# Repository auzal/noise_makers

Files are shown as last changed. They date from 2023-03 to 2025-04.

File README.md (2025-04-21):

# Protest noise makers

Simple 3D printable noise makers. Use for fighting colonialism, fascism and unfair labor practices. 

Developed during the UCLA Graduate strike of 2022. More info [here](#background).

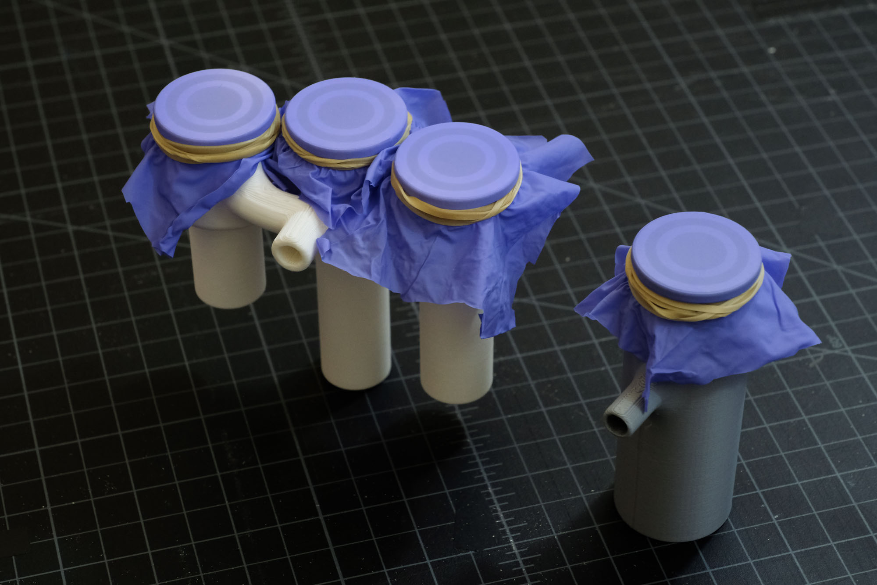
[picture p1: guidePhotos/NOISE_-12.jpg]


## Table of contents:

- [3D printable files](#3d-printable-files)
- [Assembly guide](#assembly-guide)
- [Test videos](#test-videos)
- [Design](#design)
- [Variations](#variations)
- [Earlier versions](#earlier-versions) 
- [Background](#background)

## 3D printable files

Ready to print .stl files are located in the [3DprintFiles](3DprintFiles) directory. 

There are several files that are ready to print: 
- [NoiseMakerSimpleV2.stl](3DprintFiles/NoiseMakerSimpleV2.stl) is a single chamber model. Easiest and quickest to print. This is a slightly improved version that uses less material and prints faster.
- [NoiseMakerTriple.stl](3DprintFiles/NoiseMakerTriple.stl) is a triple chamber model. Much louder and creates a poly tonal sound. Uses much more material to print. 
- [NoiseMakerSimpleV2Large.stl](3DprintFiles/NoiseMakerSimpleV2Large.stl) is a larger version of  the single chamber model. 
- [NoiseMakerSimpleV1_olderVersion.stl](3DprintFiles/NoiseMakerSimpleV1_olderVersion.stl) is an older version of the single chamber model (the one referenced in the guide photos below). It's a little less efficient than the V2 files. 

It's better if the files are printed with support material for the mouthpiece only. This can be done by using support painting or a similar tool (dependent on your 3D printing software)

## Assembly guide

A video of the assembly process can be found [here](https://youtu.be/jMzxnDv2O78)

#### Step 1 - Print a noise maker body
These devices are printed as a single piece. 
Some notes on the printing process:
- all tests have been made with PLA
- prints have been tested up to .28 mm layer height. They should work up to .4 mm
- the mouthpiece will need supports. Make sure to not include support inside the chambers or it may be difficult to remove
- an infill of about 15% is more than enough

#### Step 2 - Gather materials
To build a noise maker, you will need:
- a 3D printed noise maker body (using the single chamber model for this guide)
- some sandpaper (something like 150 grit works well)
- a pair of scissors
- a rubber band
- a nitrile glove (latex gloves, balloons, or plastic bags can also be used. Different materials will produce different timbres) 

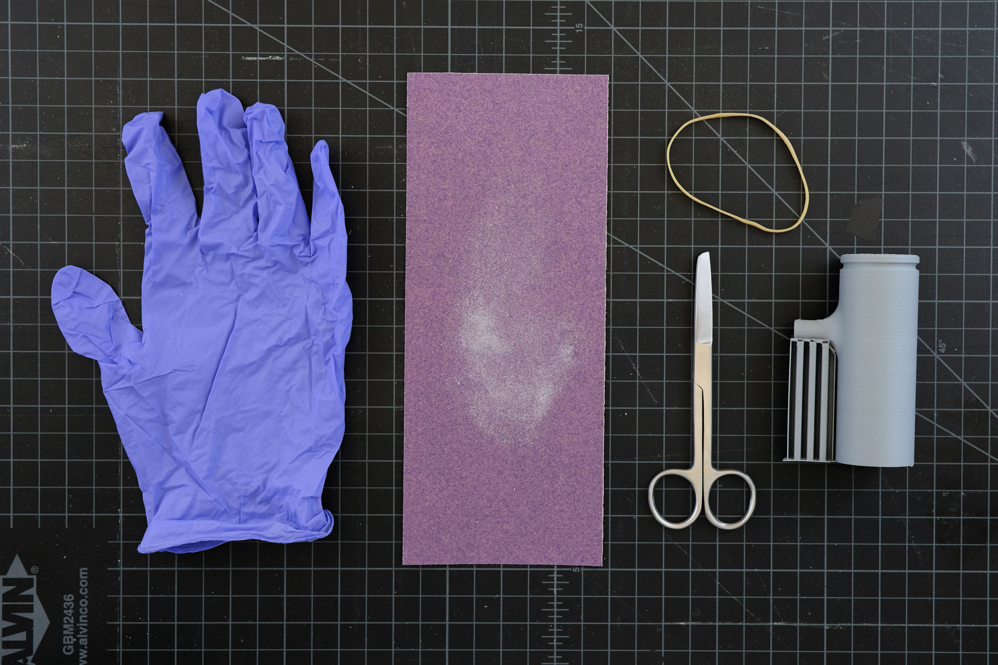
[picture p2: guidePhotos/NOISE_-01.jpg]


#### Step 3 - Remove supports from 3D printed body
 
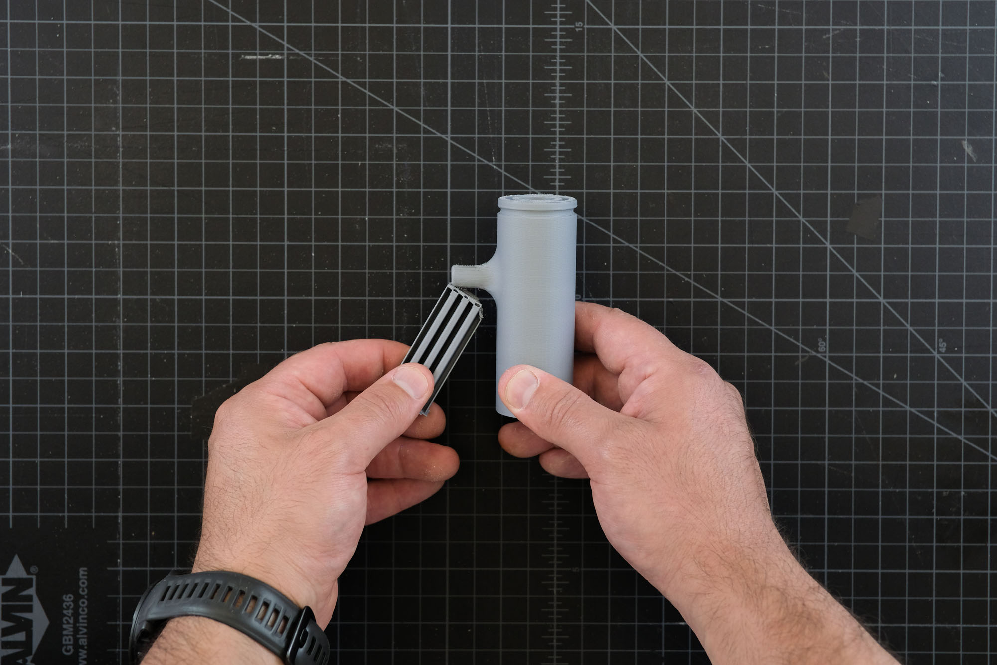
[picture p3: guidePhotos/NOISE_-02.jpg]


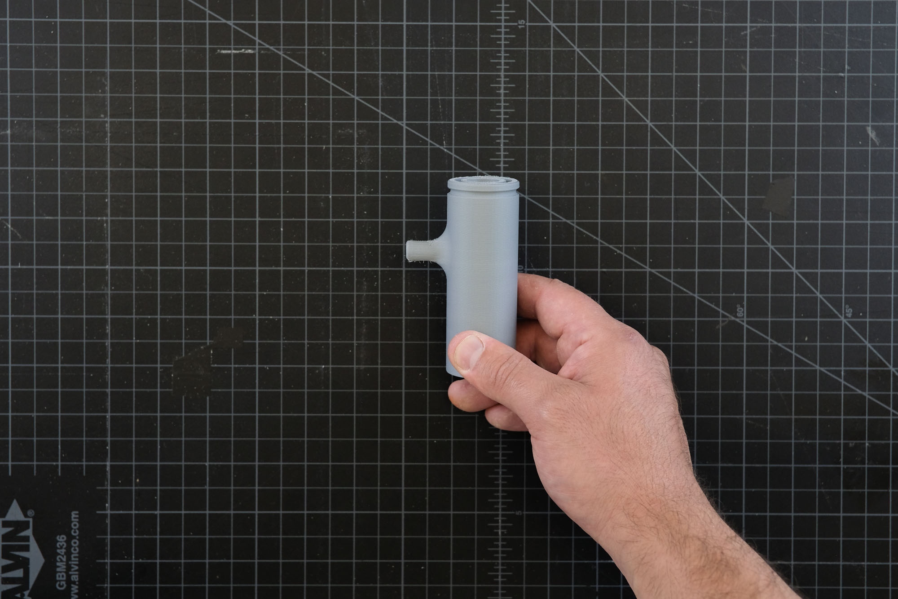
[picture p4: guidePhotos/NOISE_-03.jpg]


#### Step 4 - Sand the upper end of the body, until there are no sharp irregularities

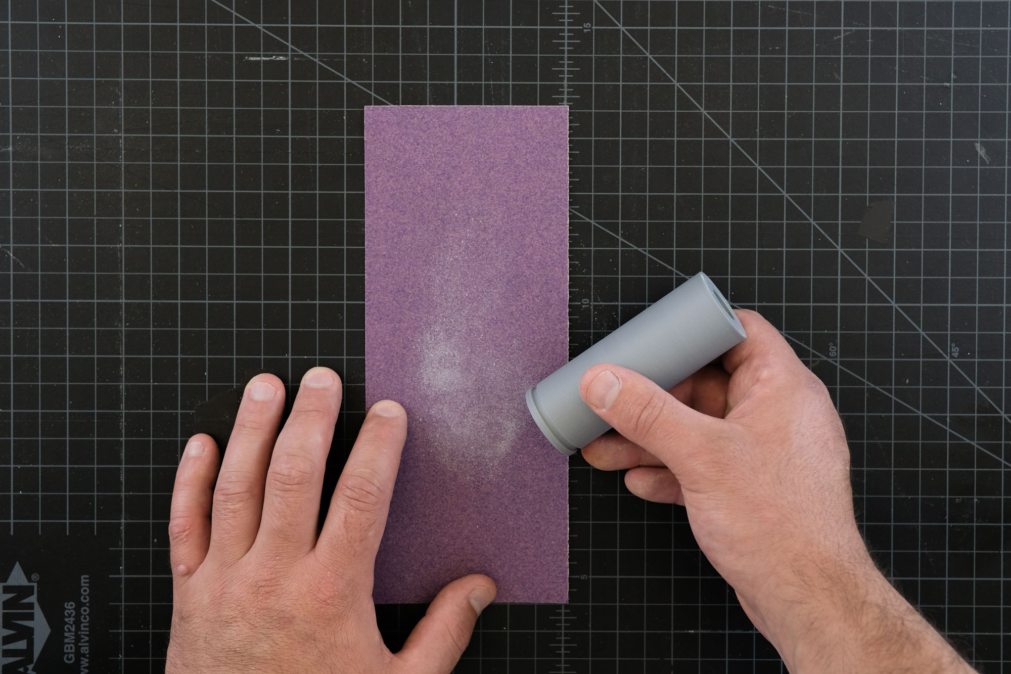
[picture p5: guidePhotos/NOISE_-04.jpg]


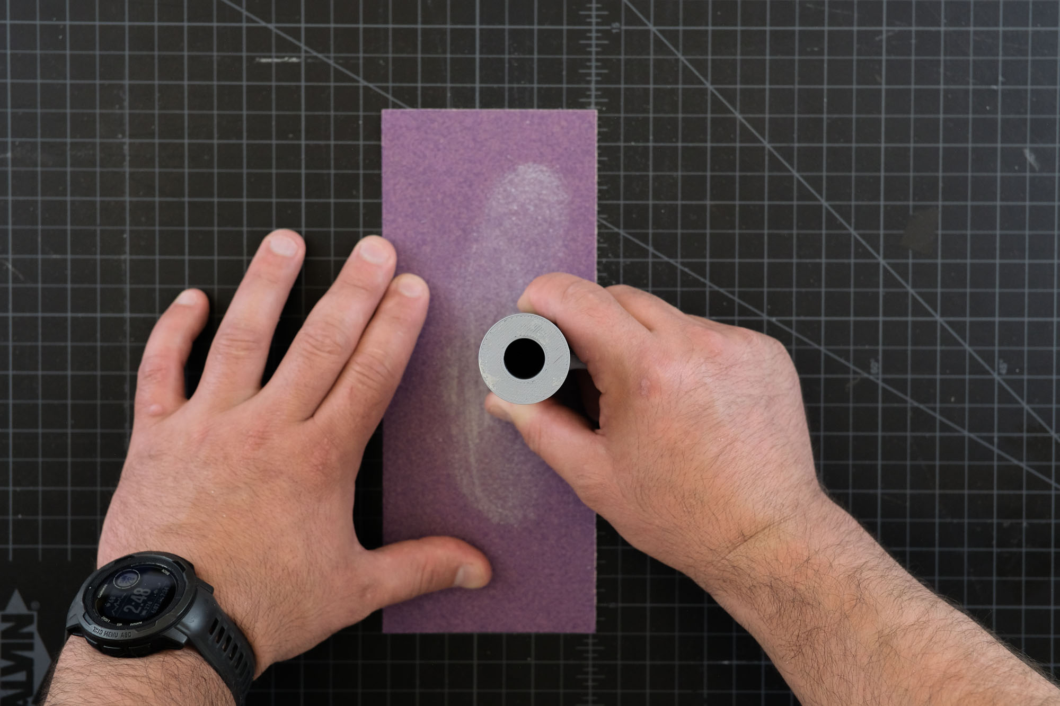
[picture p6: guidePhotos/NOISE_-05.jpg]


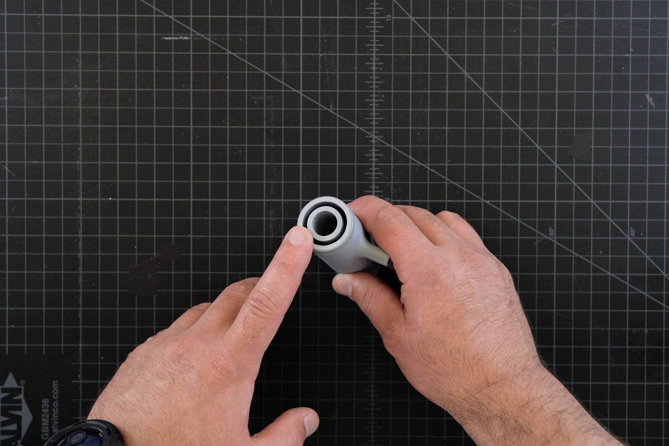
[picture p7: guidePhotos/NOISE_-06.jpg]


#### Step 5 -  Cut a square of material from the glove. It needs to be bigger than the diameter of the body. This will act as the vibrating membrane.

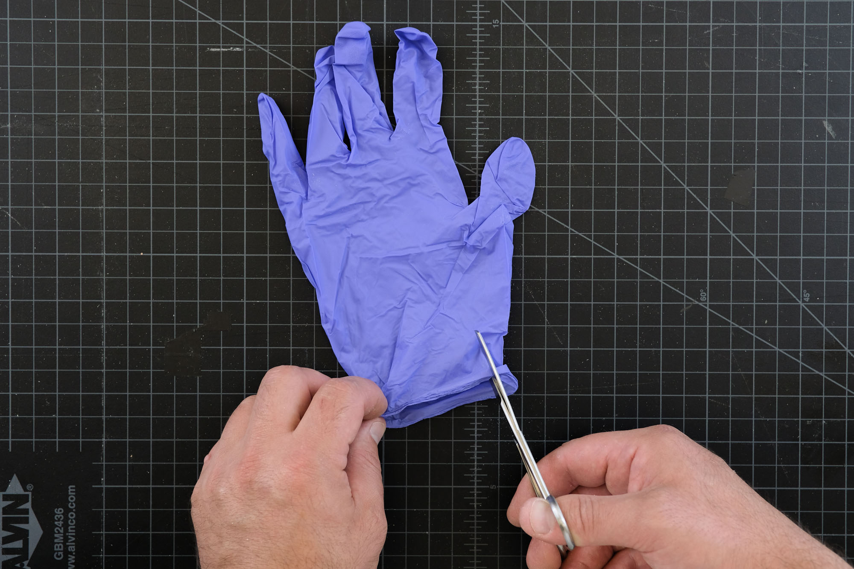
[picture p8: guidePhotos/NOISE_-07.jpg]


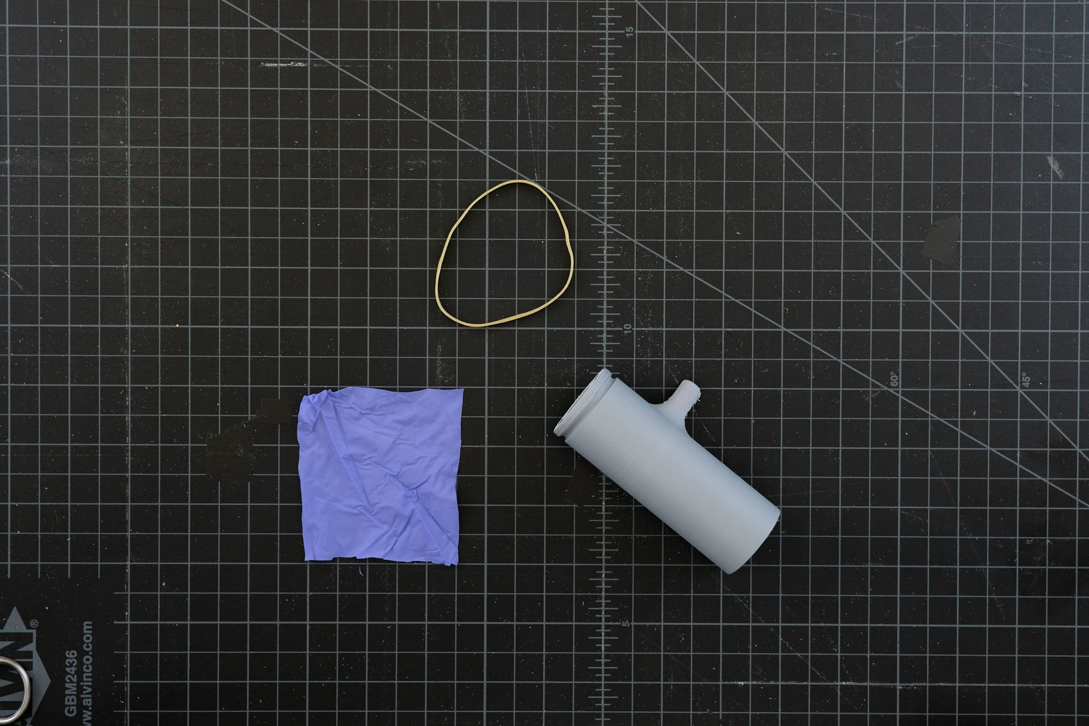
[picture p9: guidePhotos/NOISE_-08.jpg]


#### Step 6 - Stretch the membrane over the sanded end

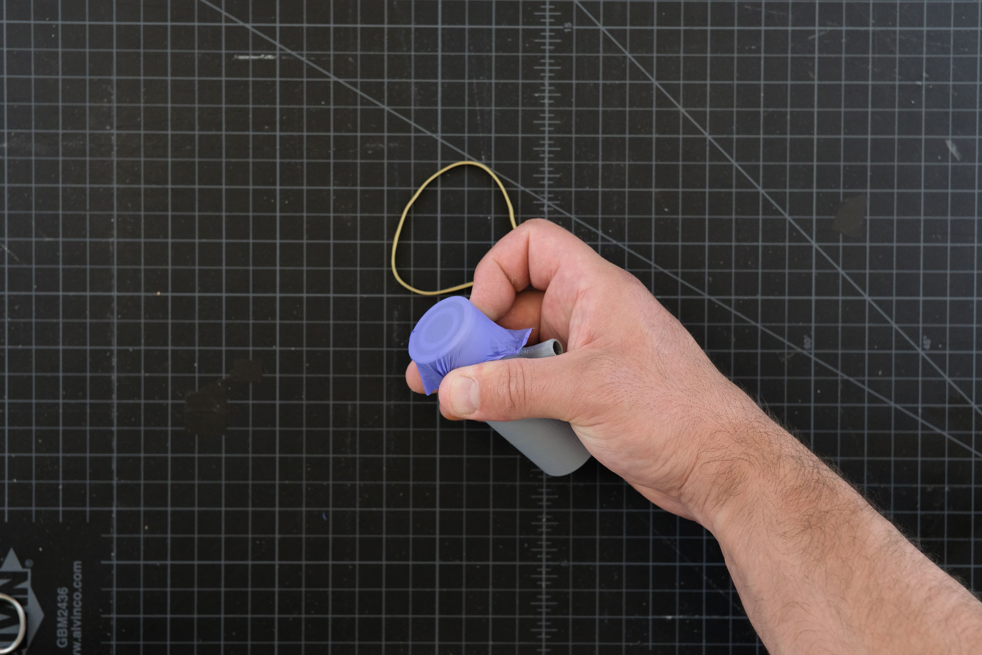
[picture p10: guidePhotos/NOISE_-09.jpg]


#### Step 7 - Secure the membrane with the rubber band. Make sure it's tight and that there are no creases.

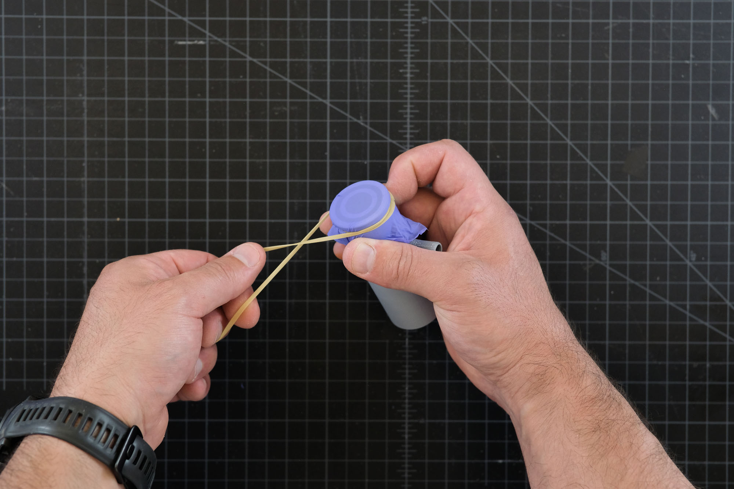
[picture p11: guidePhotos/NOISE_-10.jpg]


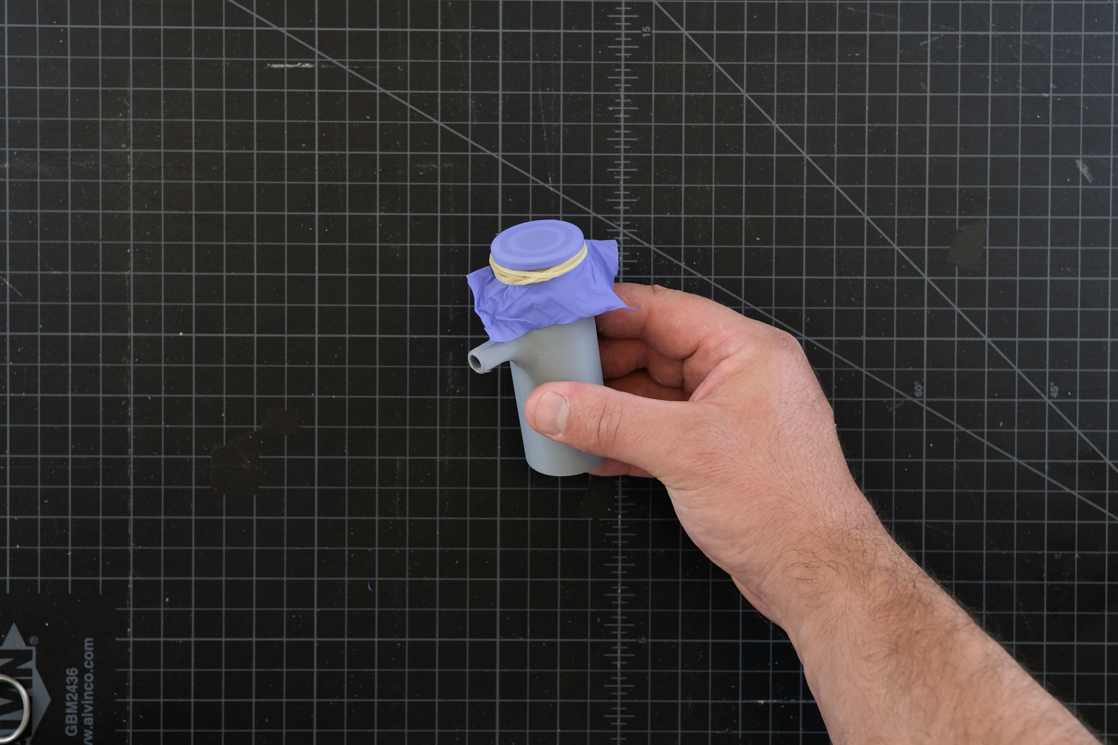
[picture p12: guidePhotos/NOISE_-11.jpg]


### Done!

## Test videos

https://github.com/auzal/noise_makers/assets/3940167/49ffc315-b2f3-4ef4-8d3e-ae68fc700136

Testing the single chamber version

https://github.com/auzal/noise_makers/assets/3940167/70f62b58-36f9-45e0-9690-6776add53538

Testing the triple chamber version

## Design

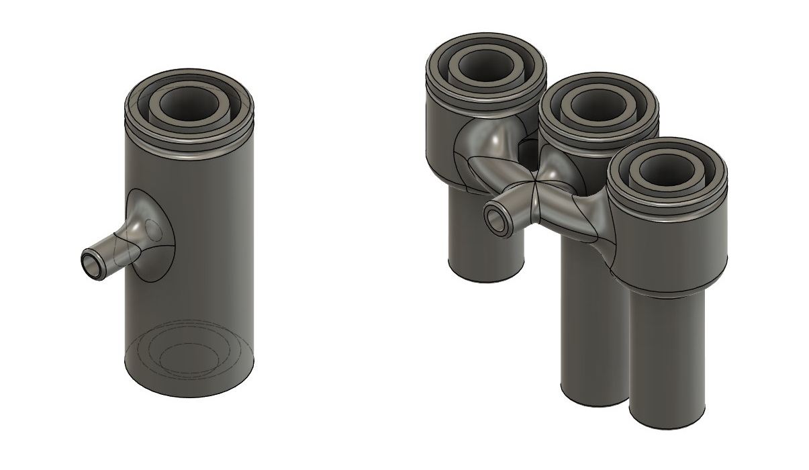
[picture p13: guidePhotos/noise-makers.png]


These devices work by blowing air through the mouthpiece. The air is then forced through an elastic membrane, which vibrates and pushes the air out of the inner tube, creating a loud sound. 

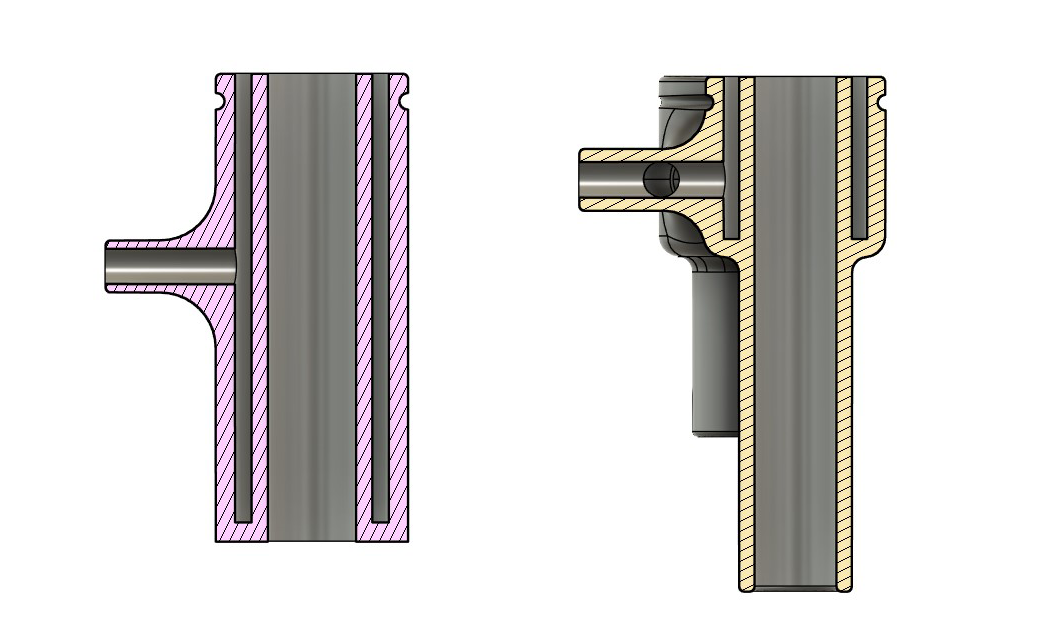
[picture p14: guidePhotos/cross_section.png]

Cross section view of both devices

These devices were modeled in Fusion 360. The design files can be found in the [fusionFiles](fusionFiles) directory. 

### Some notes on the Fusion files:
- changing the diameter of the chambers will affect the amplitude of the sound
- changing the length of the inner tube will affect the pitch (shorter tube means higher pitch)
- on the triple chamber design, the length of each inner tube can be adjusted individually
- the design is parametric, so dimensions are easy to change:
    - in the *Solid* tab, go to Modify > Change parameters 
    - from here you can adjust the diameter and overall length of the noise maker

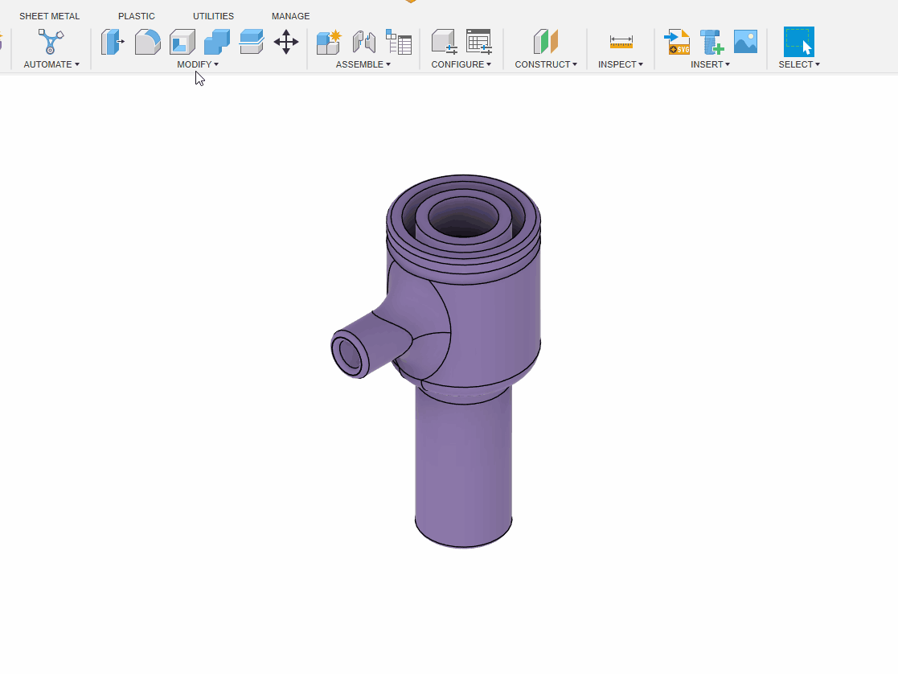
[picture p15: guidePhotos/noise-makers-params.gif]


## Variations

The single chamber noise maker can be printed to fit directly on different cylindrical objects. This will allow you to achieve lower frequencies and louder volumes. Experiment with what you have around! Make sure you seal the joint so no air can escape. 

### Bass version

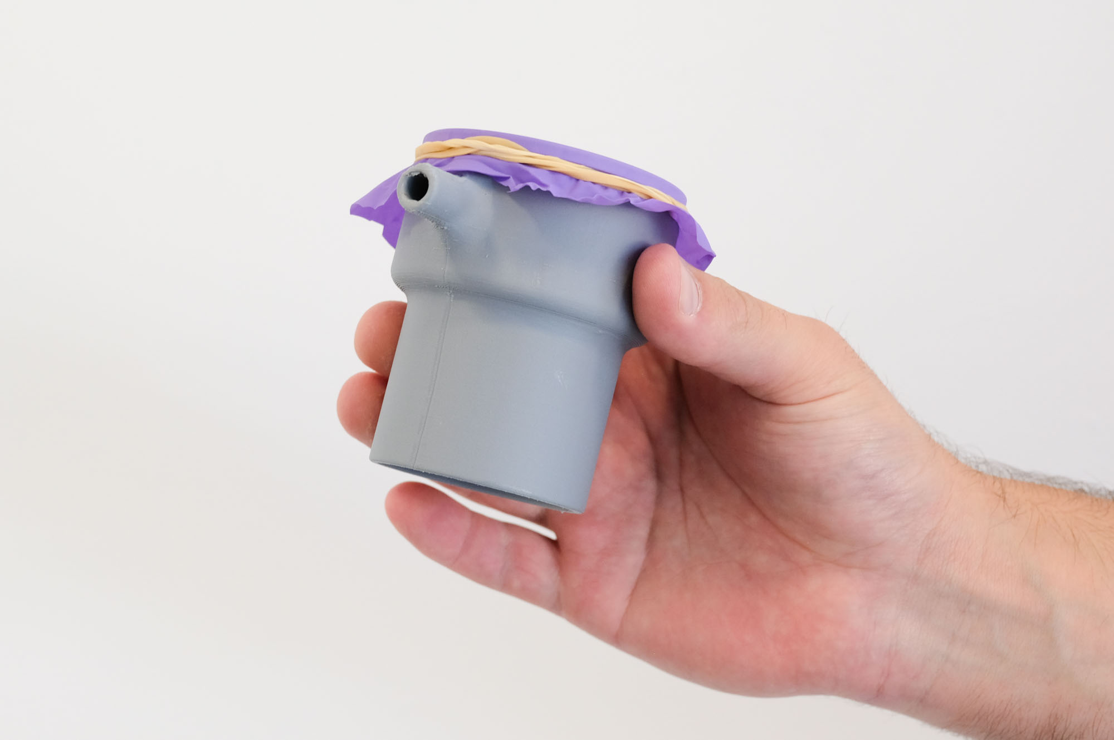
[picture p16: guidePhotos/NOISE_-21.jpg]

Single chamber design sized to fit into a 2 inch PVC pipe.

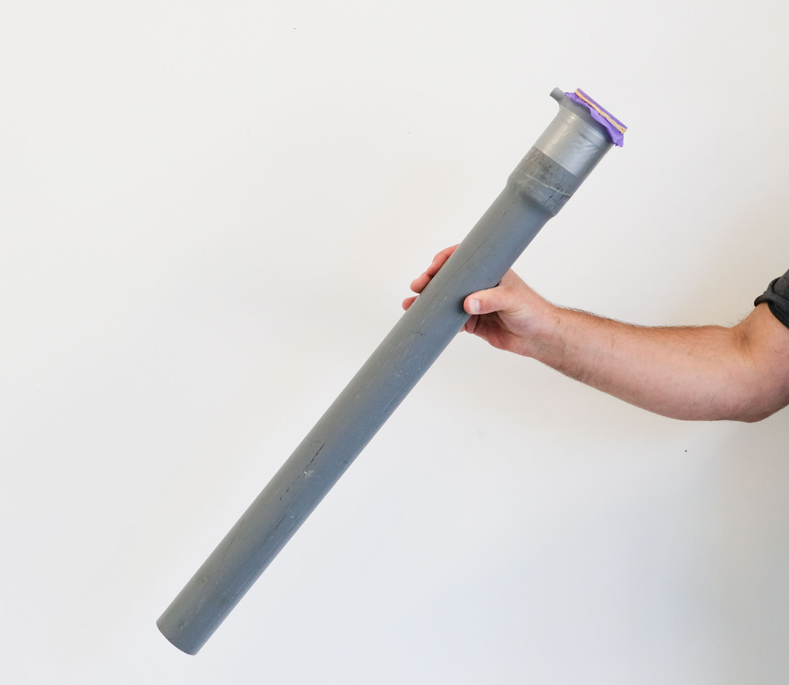
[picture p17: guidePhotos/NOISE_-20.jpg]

Fitted into a section of pipe and sealed in place with duct tape.

https://github.com/auzal/noise_makers/assets/3940167/308d74f6-2402-479b-8176-515639adbdc4

### Sliding bass version

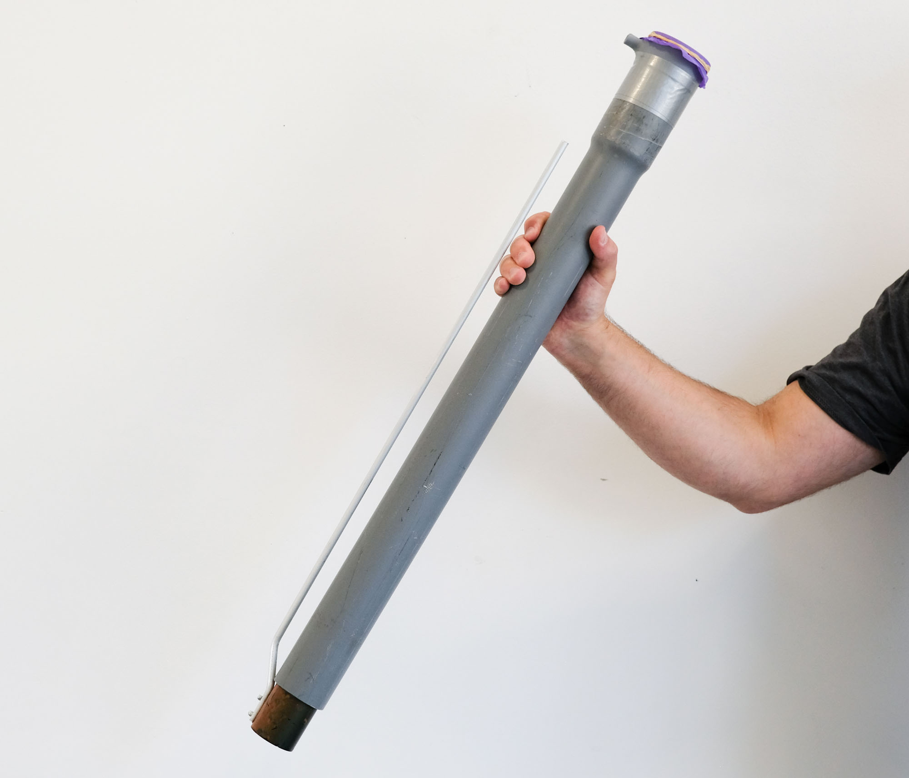
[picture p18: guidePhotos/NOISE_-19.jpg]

Same as above, but with a section of narrower pipe (fitted with a handle), that can slide to alter the pitch as it is being played (the longer the pipe, the lower the pitch).

https://github.com/auzal/noise_makers/assets/3940167/3bd1a570-b454-4dcb-a997-6549486a73a5

### Water jug version

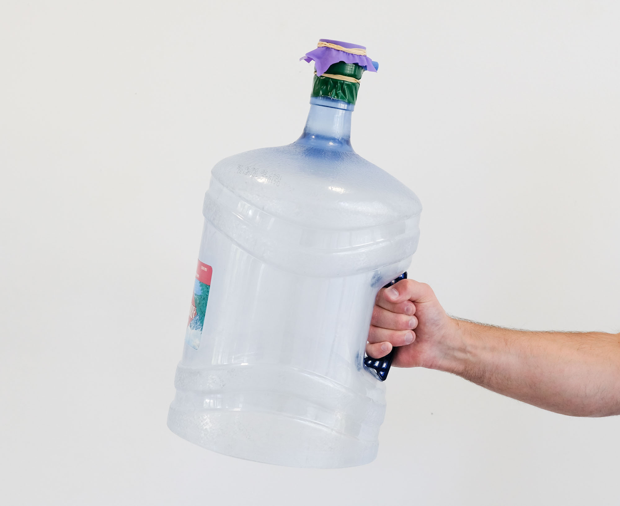
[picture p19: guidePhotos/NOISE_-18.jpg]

Single chamber design sized to fit into a plastic 5 gallon water jug. 

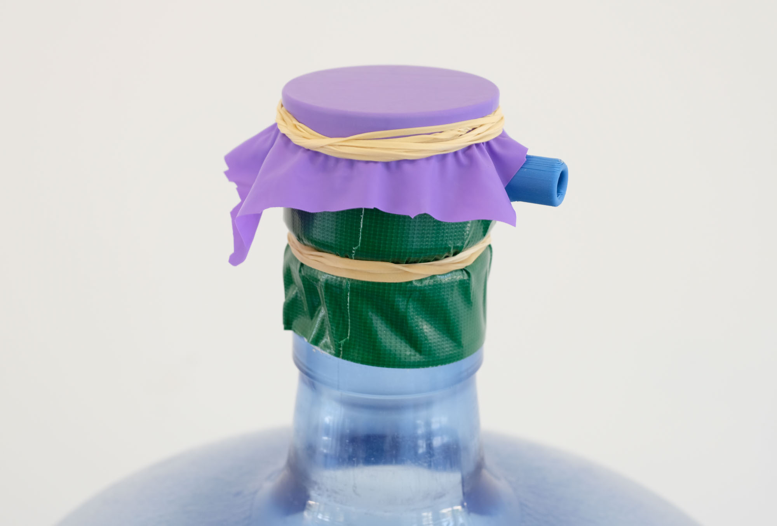
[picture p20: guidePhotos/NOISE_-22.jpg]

Sealed with duct tape and several rubber bands.

https://github.com/auzal/noise_makers/assets/3940167/67fd31fe-8686-4035-b40f-396b7f1409d7

## Earlier versions

Initial versions of the noise makers, made with nitrile gloves, different cylinders, sections of think plastic hose, and plastic bushings. They are played by stretching the glove over the cylinder to create a tense membrane, and blowing into one of the glove fingers. 

These designs are a little more bulky and the gloves tend to break easily. 

### Simplest glove noise maker
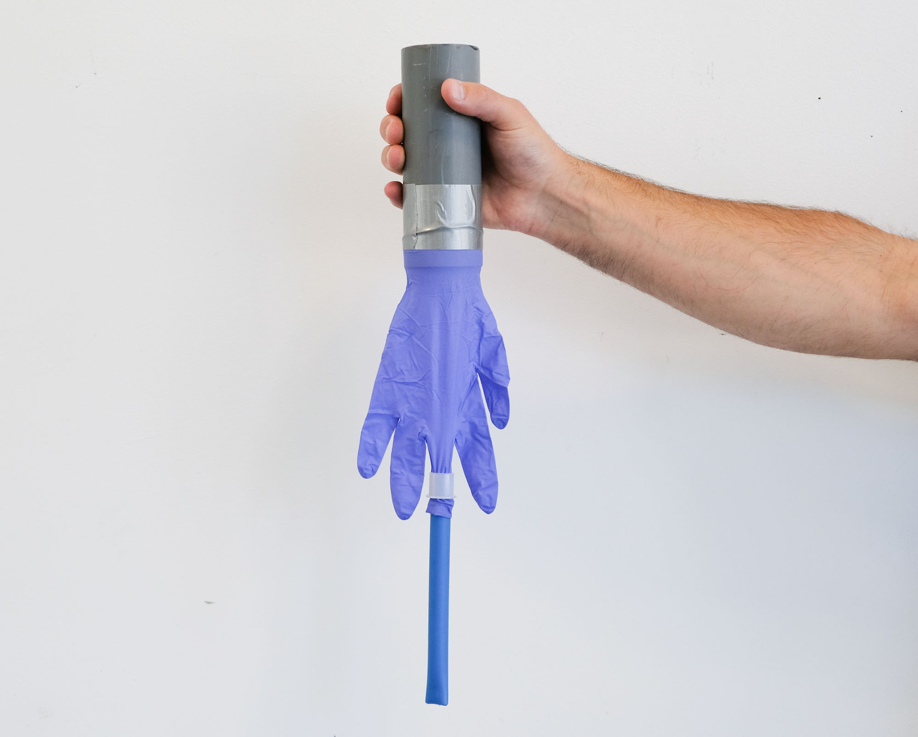
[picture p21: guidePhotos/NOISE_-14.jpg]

Simple design with a short section of 2 inch PVC pipe. 

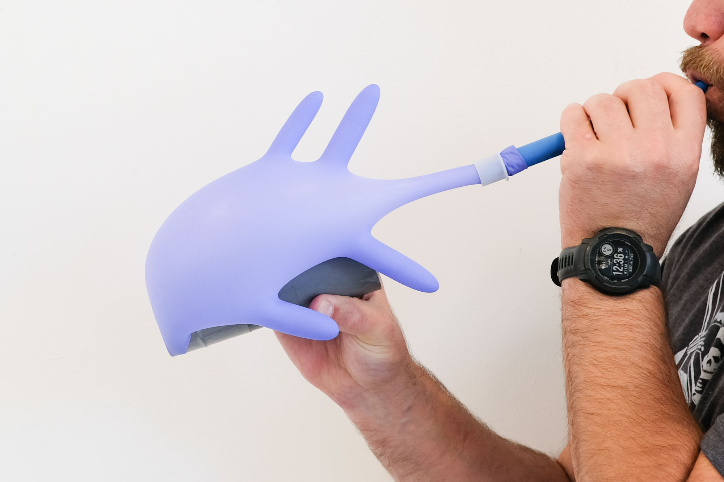
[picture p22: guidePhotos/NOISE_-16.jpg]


https://github.com/auzal/noise_makers/assets/3940167/2ded6478-1d6d-43bf-803e-398daab9d750

### Double glove noise maker

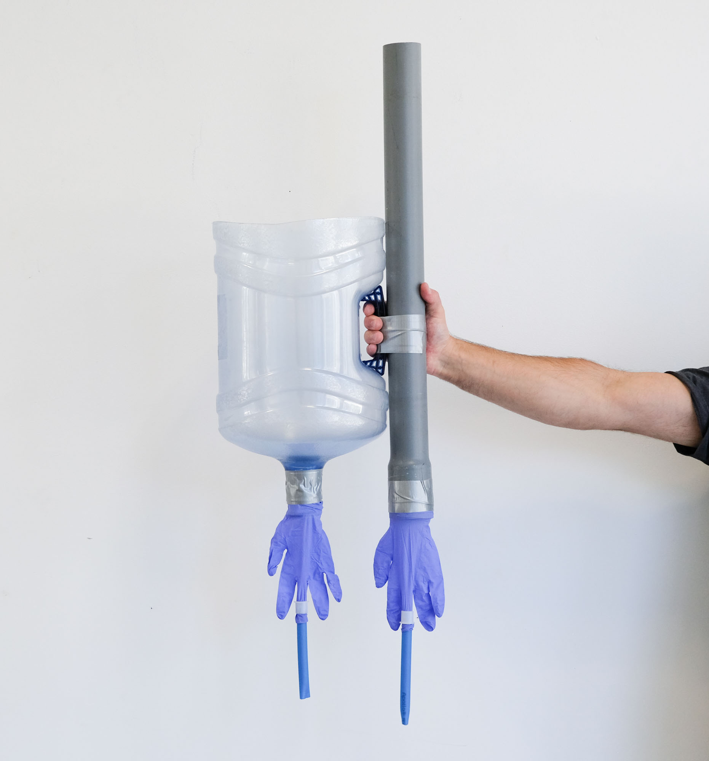
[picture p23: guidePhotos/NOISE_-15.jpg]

Two noise makers taped together create different tones (and offer more visual impact!).

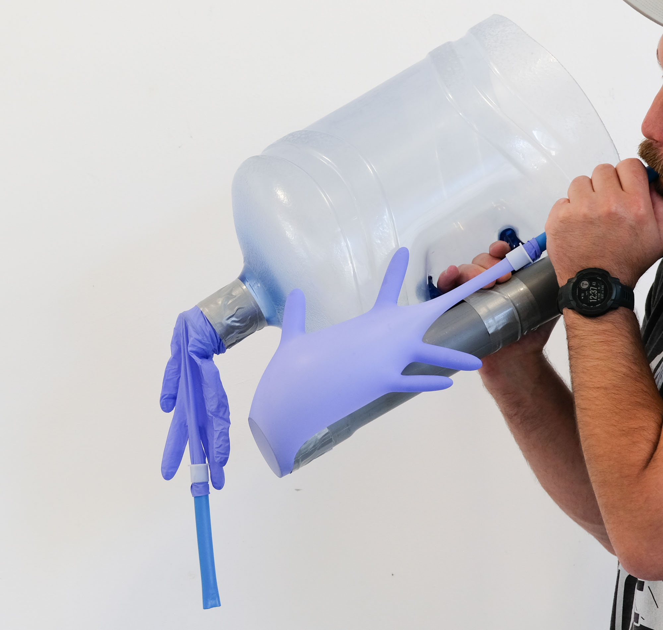
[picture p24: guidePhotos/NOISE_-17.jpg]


https://github.com/auzal/noise_makers/assets/3940167/32b1c8c3-c968-47c1-9769-f9f9e4fa35f9

## Background

While on a rally during the [2022 University of California academic workers' strike](https://en.wikipedia.org/wiki/2022_University_of_California_academic_workers%27_strike), my friend (and fellow UCLA DMA graduate student) [Wiley Wiggins](https://wileywiggins.com/) and I saw some some other students with noise makers made out of paper towel tubes. We took note of the design and began experimenting in our department's fabrication laboratory to make similar devices. The initial version of these devices was bagpipe-like, made from discarded cardboard tubes and rubber gloves (as featured [above](#earlier-versions)). Wiley and I hosted a couple of sessions in the lab to show other students how to build the noise makers. 

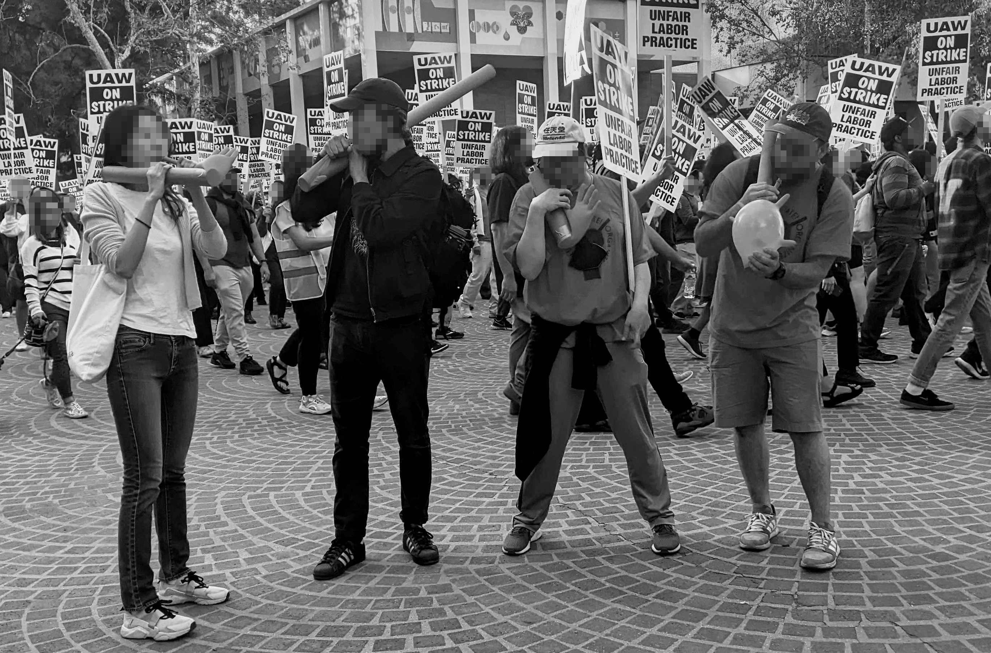
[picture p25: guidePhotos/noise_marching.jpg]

DMA marching band during the 2022 strike

As the strike continued, I kept working through iterations of these noise makers, eventually arriving at a version that is compact, easy to make and produces very loud sounds. The final design is meant to be easy to conceal, small enough to be used with one hand, and simple and cheap to reproduce (it can be created out of PVC pipes, or 3D printed as a single part).

 These noise making objects serve several purposes. In terms of sound and its relation to protest, they allow us to be heard (by us -those who are protesting- and by them -those who we stand against-), they are political in their design and creation, they serve to unite through their sound (they act as beacons of togetherness and safety), and they allow for disruption. Additionally, they are tools for communal play and experimentation. They can be gifted, shared freely, and played with others. 
 
 Their compact size and portability also grant them an amulet-like quality, an object one may hold closely in difficult times. Cecilia Vicuña speaks of the multidimensionality of objects in her 1973 book “Saborami”[^1]:

> “Los objetos tratan de matar tres pájaros de un solo tiro: hacer un trabajo mágico, uno revolucionario y uno estético. ” (“Objects try to kill three birds with one stone: they do magical wok, revolutionary work, and aesthetic work.”)

She refers to “un golpe mágico que es ayudar a la liberación” (“a magical strike that helps liberation”), “un golpe politico” (“a political strike”) that is revolutionary, and “un golpe estético: tienen que ser bellos para darle fuerza al alma” (“an aesthetic strike: they -objects- must be beautiful to give strength to the soul”).

[^1]: Vicuña, Cecilia, and Felipe Ehrenberg. Saborami. Beau Geste Press, 1973.

### An expaned version of this text can be found [here](Uzal-Notes-on-sound.pdf)

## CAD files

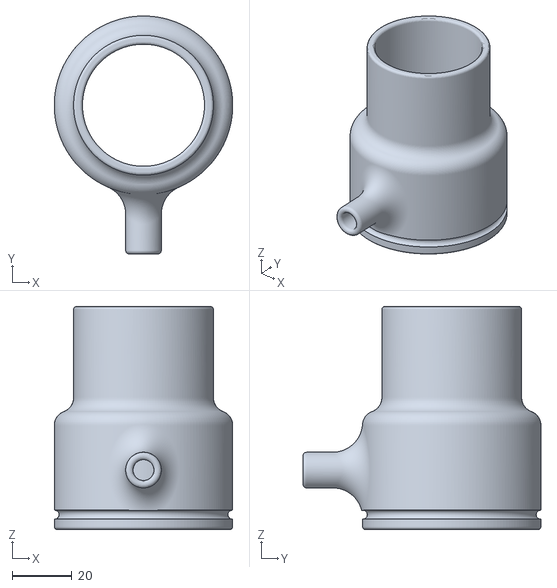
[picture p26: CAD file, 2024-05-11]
3DprintFiles/NoiseMakerSimpleV2Large.stl
60.0 x 80.0 x 75.0

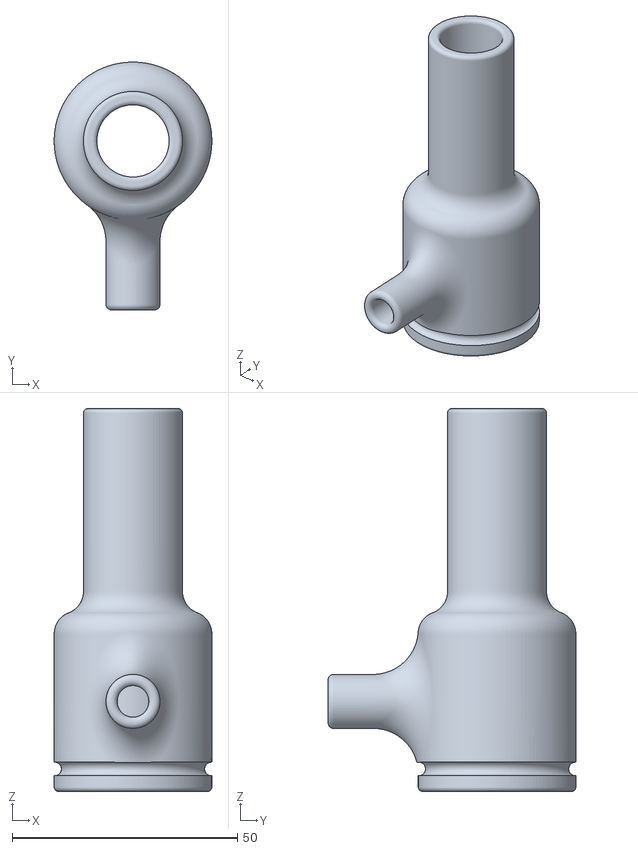
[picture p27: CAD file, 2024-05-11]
3DprintFiles/NoiseMakerSimpleV2.stl
35.0 x 55.0 x 85.0

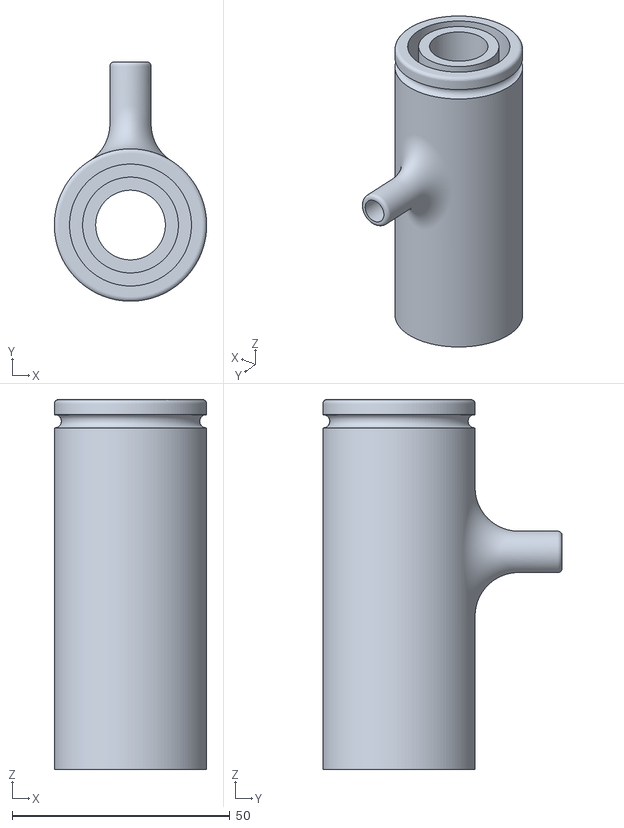
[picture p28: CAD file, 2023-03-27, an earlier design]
3DprintFiles/NoiseMakerSimple.stl
35.0 x 55.0 x 85.0

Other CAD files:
fusionFiles/NoiseMakerSimple.f3d
fusionFiles/NoiseMakerSimpleV1_olderVersion.f3d
fusionFiles/NoiseMakerTriple.f3d
fusionFiles/noiseMakerSimpleV2.f3d

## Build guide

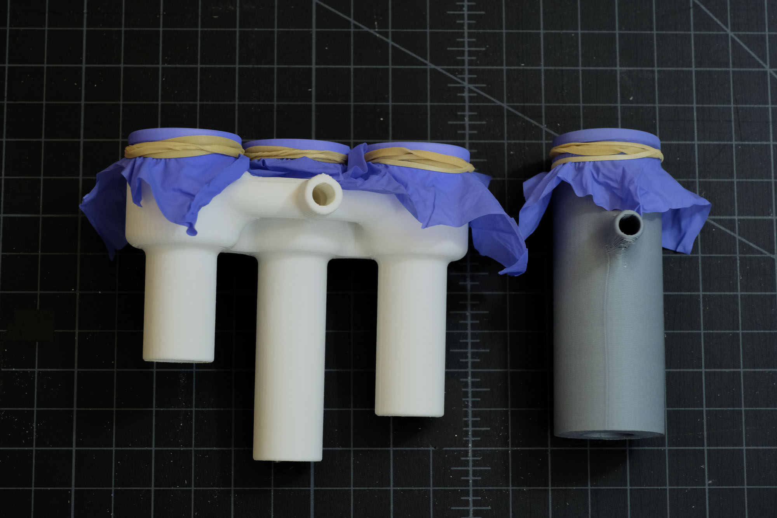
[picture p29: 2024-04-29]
guidePhotos/NOISE_-13.jpg

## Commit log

2024-04-29 added media
    [NoiseMakerSimple.f3d, NoiseMakerSimple.stl, NoiseMakerTriple.f3d]
2024-04-29 dumb filename fix
    [NoiseMakerSimple.f3d, NoiseMakerSimple.stl, NoiseMakerTriple.f3d]
2024-05-11 new files and more documentation
    [NoiseMakerSimpleV1_olderVersion.f3d, NoiseMakerSimpleV1_olderVersion.stl, NoiseMakerSimpleV2.stl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]
